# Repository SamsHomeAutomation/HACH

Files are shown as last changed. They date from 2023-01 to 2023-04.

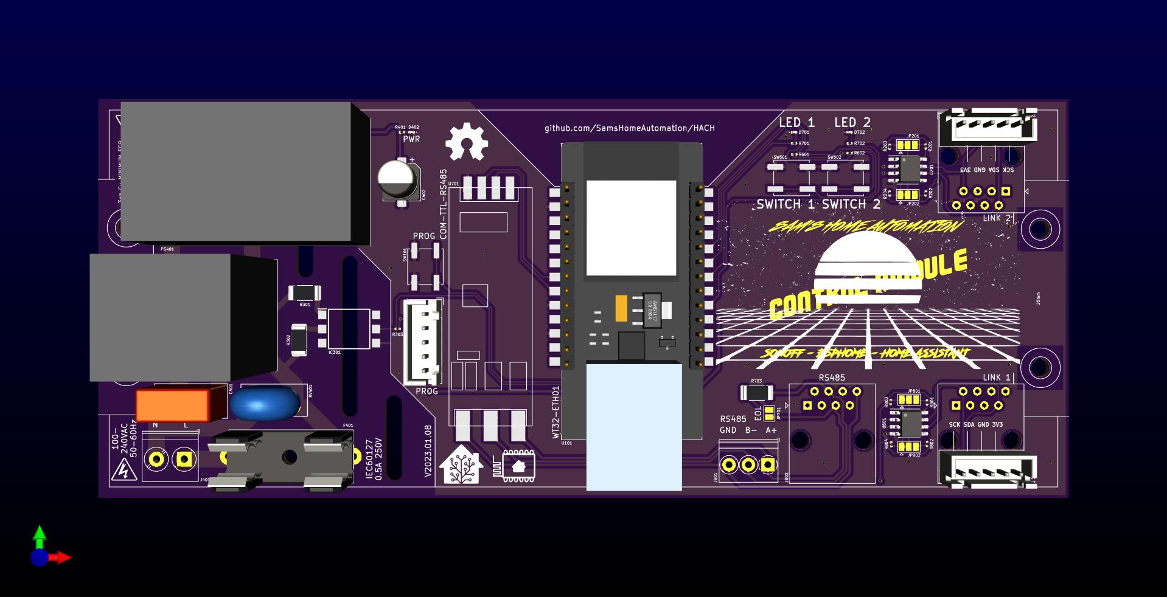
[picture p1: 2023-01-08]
3D RENDERS/Control Module.jpg

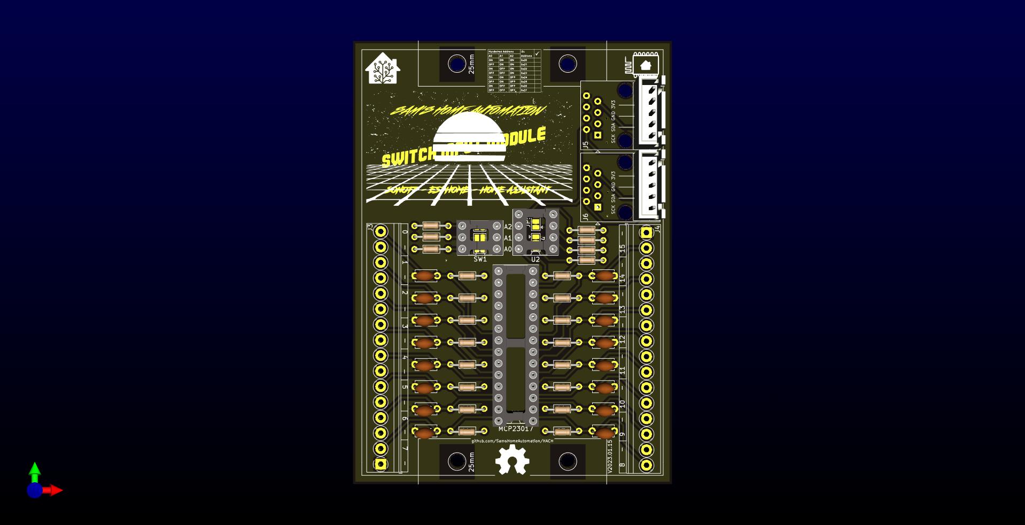
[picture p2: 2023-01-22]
3D RENDERS/Switch Inputs Module THT .jpg

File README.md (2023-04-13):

# HACH
Home Automation Control Hardware

Introduction:
We are developing a Home Automation Control Hardware, which consists of a Control Module and Extension Modules that allow for the control of lighting and other equipment through ESPHome and Home Assistant.

Control Module:
The Control Module is the main component and includes an esp32 microcontroller, ethernet and RS485 ports, zero-cross detection, and i2c link ports with extender chips. It also has two programmable LEDs, two tactile switches, and a programming header. The board is powered by a 100-240VAC supply, while the link power to extension modules and all other board power is 3.3V. The RS485 port enables communication with modbus enabled equipment such as solar PV systems. The Control Module is designed to run ESPHome firmware.

SSR Output Module:
This module can be linked to the Control Module using an RJ45 patch lead and can be used to switch or dim mains voltage lamps up to 2 amps. All eight output channels are individually fused and controlled.

Switch Input Module:
The Switch Input Module is used to attach standard toggle light switches, retractive light switches, push buttons, and dry contacts volt-free contacts. All 16 inputs have hardware pullup and debounce, and each input has two screw terminals for common ground and input signal. The module can be linked to the Control Module using an RJ45 patch lead.

Switch & SSR Module:
This module is a combination of the SSR Output Module and the Switch Input Module, featuring 12 inputs and 4 outputs. It can be linked to the Control Module using an RJ45 patch lead.

4chPro Adapter:
The 4chPro Adapter allows the use of a Sonoff 4ch Pro as the Control Module, expanding its capabilities by adding the Switch Inputs Module, SSR Output Module, and/or the Switch and SSR Module. The adapter is soldered to the program port inside the Sonoff and provides an RJ45 link port.

Mounting:
All boards are designed to fit in Phoenix Contact UM 72 profile din rail mounts and can be mounted inside a control panel. The hardware is versatile and can be used for many tasks other than just lighting, such as heating controls.

Development:
Our hardware is still in the development stage, with PCBs currently being designed. We plan to produce some prototype boards for bench testing in early 2023, with small production runs for sale in the future.

Conclusion:
If you have any questions, comments, suggestions for improvement, or ideas for more modules, please feel free to create a discussion. We will try our hardest to answer everyone.

--UPDATE 22.01.2023--
The through hole version of the Switch Input module has been sent off to PCBWay to be printed. this will be tested within the next month.
This module is compatible with sonoff 4ch pro and other sonoff models with custom made link cable. The 4ch pro link modules have also been sent off to print.
The 4ch pro link module makes for a easy reliable connection to a sonoff 4ch pro by way of an rj45 connector. This is experimental and testing will be carried out within the next month.
All Gerber files for Switch Input Module through hole version are now available to use.

--UPDATE 13.04.2023--
Unfortunately I no longer have the time to put into this project. If anyone wants to continue with it please do contact me via github or email.
The switch input pcb I have built is working fine with a slight bodge as I missed the reset line for the mcp23017. The i2c extender does not appear to work so needs more experimenting. But normal ttl level i2c works just fine. the sonoff pro link pcb are too big and need complete redesign.

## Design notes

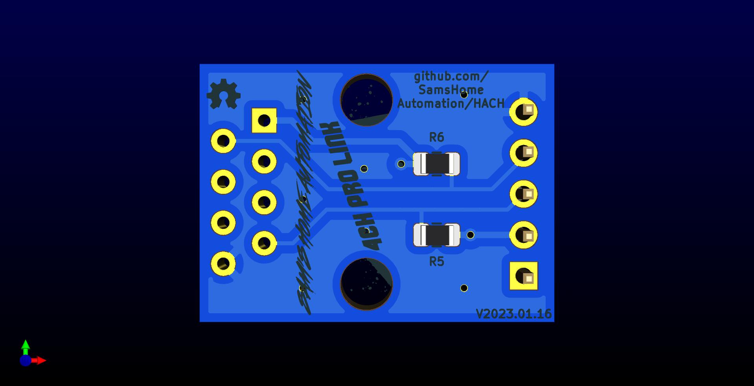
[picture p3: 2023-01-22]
3D RENDERS/4chPro Adapter without IC.jpg

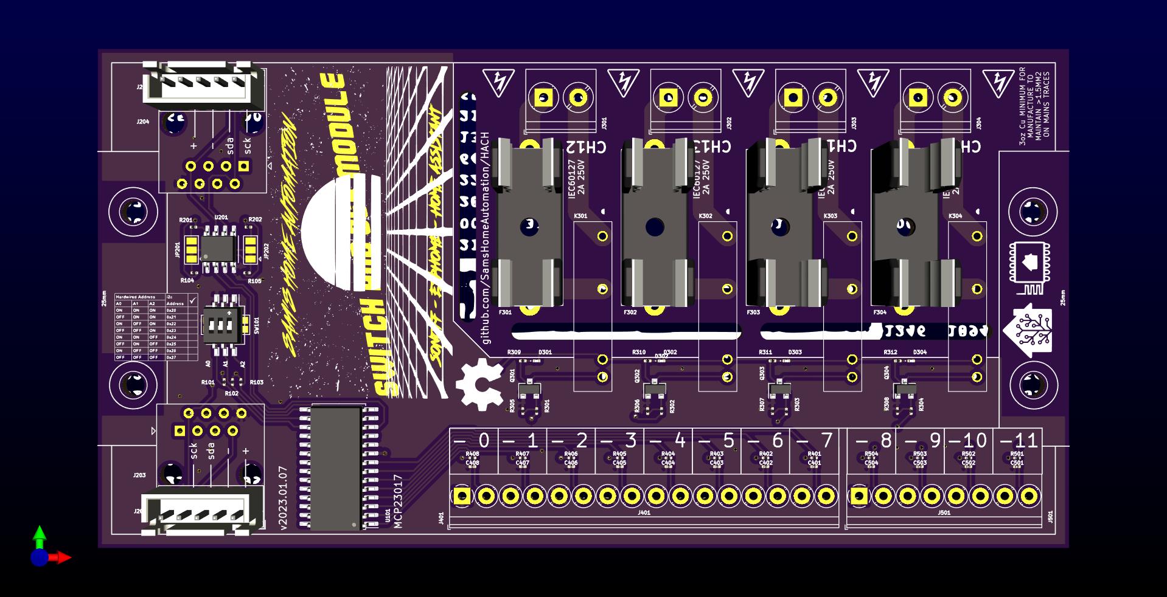
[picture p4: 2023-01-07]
3D RENDERS/Switch & SSR Module.jpg

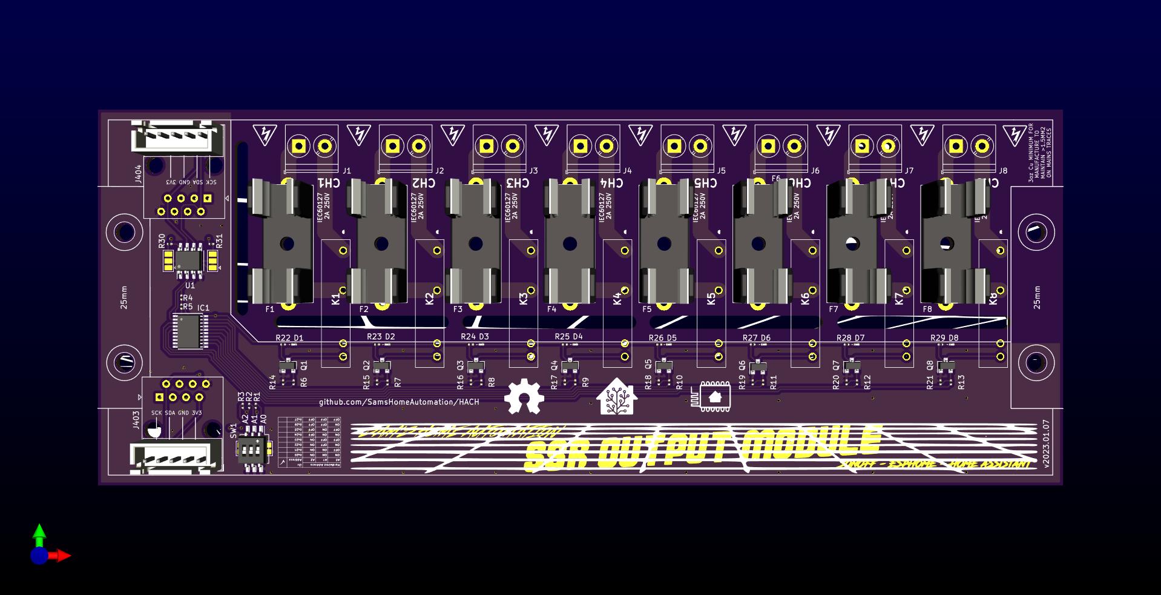
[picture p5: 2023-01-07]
3D RENDERS/SSR Output Module.jpg

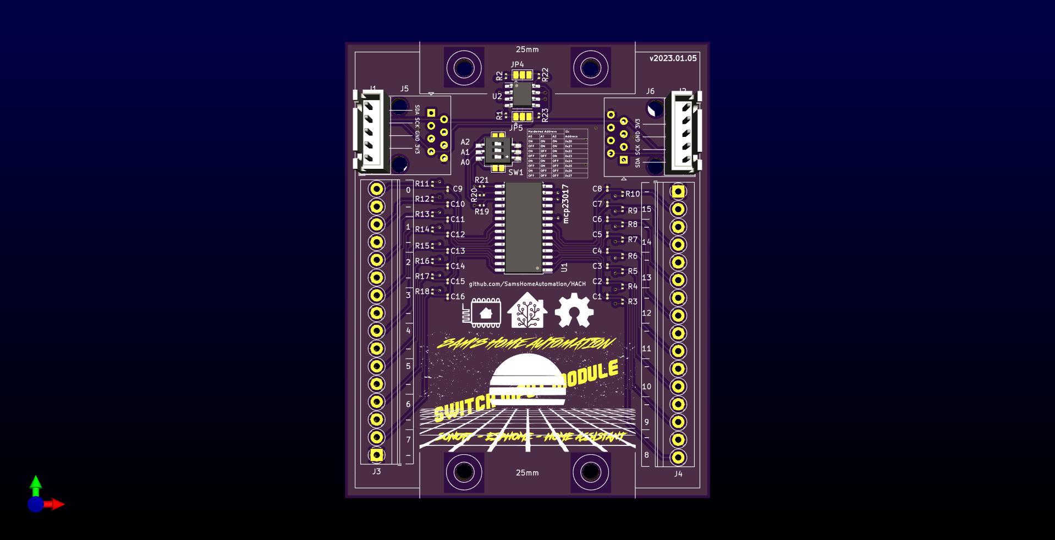
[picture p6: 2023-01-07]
3D RENDERS/Switch Inputs Module.jpg

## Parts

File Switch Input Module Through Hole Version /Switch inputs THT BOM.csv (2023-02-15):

Id | Designator | Package | Quantity | Designation
2 | 25mm,25mm | DinRailAdapter_2xM3_pheonixContact | 2 | DinRailAdapter_2xM3_pheonixContact
3 | R19,R11,R12,R13,R14,R15,R16,R17,R18,R3,R4,R5,R6,R7,R8,R9,R10,R20,R21 | R_Axial_DIN0204_L3.6mm_D1.6mm_P7.62mm_Horizontal | 19 | 10k
4 | SW1 | DIP-6_W7.62mm_Socket | 1 | SW_DIP_x03
6 | R1,R2 | R_Axial_DIN0204_L3.6mm_D1.6mm_P7.62mm_Horizontal | 2 | 4K7
7 | J3,J4 | TerminalBlock_Phoenix_PT-1,5-16-3.5-H_1x16_P3.50mm_Horizontal | 2 | Screw_Terminal_01x16
17 | U1 | DIP-28_W7.62mm_Socket | 1 | MCP23017_SP
18 | C9,C10,C11,C12,C13,C14,C15,C16,C1,C2,C3,C4,C5,C6,C7,C8 | C_Disc_D4.7mm_W2.5mm_P5.00mm | 16 | 100nF
20 | R22,R23 | R_Axial_DIN0204_L3.6mm_D1.6mm_P7.62mm_Horizontal | 2 | 430R
21 | U2 | DIP-8_W7.62mm_Socket | 1 | P82B715TD,118
22 | J1,J2 | JST_XH_B5B-XH-A_1x05_P2.50mm_Vertical | 2 | Screw_Terminal_01x05
23 | J5,J6 | RJ45_Amphenol_54602-x08_Horizontal | 2 | RJ45

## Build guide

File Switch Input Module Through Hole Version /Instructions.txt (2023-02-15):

Switch Input Module Through Hole Version

This module is designed to connect to a Sonoff 4ch Pro or other control module and is used to attach standard toggle light switches, retractive light switches, push buttons, and dry contacts volt-free contacts.

Populate PCB with the following components:

3.5mm pitch screw terminals
10k pull-up resistors
100nf debounce capacitors
MCP23017 I2C port expander
3 pole DIP switch
4k7 I2C bus resistors
470R link port bus resistors
I2C bus extender IC
RJ45 connectors
Mount the PCB on 25mm pitch DIN rail mounts or UM72 PCB DIN rail carrier.

Use an RJ45 patch lead to connect the module to the Sonoff 4ch Pro or other control module.

Attach light switches to pairs of screw terminals.

Program your controller with ESPHome and edit YAML to include MCP23017 binary inputs. For more information, please refer to esphome.io.

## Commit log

2023-01-22 Switch input tht module gerber added, 3d renders updated, instructions started
    [Switch inputs 2-B_Cu.gbl, Switch inputs 2-B_Mask.gbs, Switch inputs 2-B_Paste.gbp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]
2023-02-15 added basic BOM
    [Switch inputs THT BOM.csv]
2023-02-15 widened board to suit camden mounts
